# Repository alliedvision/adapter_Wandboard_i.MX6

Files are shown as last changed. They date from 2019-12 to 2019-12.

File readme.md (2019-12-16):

# Allied Vision Adapter Board CSI-2 for Wandboard i.MX6

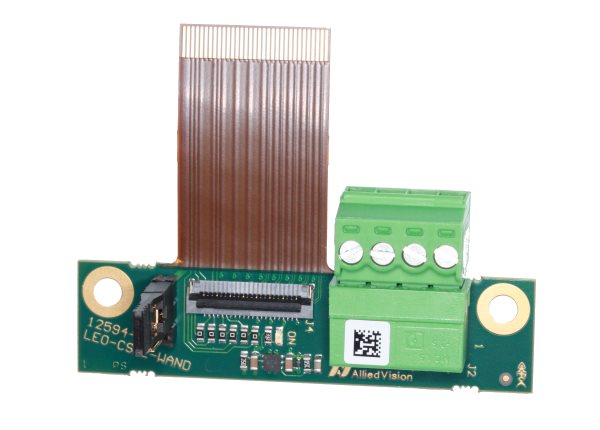
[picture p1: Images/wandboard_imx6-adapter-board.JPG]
wandboard_imx6-adapter-board


This repository contains open hardware design files for an adapter board supporting the Allied Vision Alvium CSI-2 camera pinout to Wandboards i.MX6 based devices, created by Allied Vision.
The board allows the user to interface with one Alvium MIPI CSI-2 compatible camera over a Flexible Flat Cable (FFC) connector.

This adapter can also be ordered at [Allied Vision](https://www.alliedvision.com/en/meta-header/contact-us/contact-sales.html) or a [qualified Allied Vision distributor](https://www.alliedvision.com/en/about-us/where-we-are.html) under order code **12362** - Adapter Board CSI-2 Wandboard.

## Getting Started

These instructions will get you a copy of the design files to make your own adapter boards for development and testing purposes. 
The board can be produced and assembled using the provided design files. Please take a look at the mechanical layers for more information regarding the PCB stackup recommended for fabrication. 

See our [website](https://www.alliedvision.com/en/support/technical-documentation/alvium-csi-2-documentation.html) for further documentation and installation guides of the finished boards.

### Prerequisites

* A running installation of Altium.
* A PCB producer & PCBA manufacturer or some soldering skills.
* One supported embedded board Wandboard i.MX6 series, revision D:
	* Wandboard Solo (i.MX6) WB-IMX6S-BW
	* Wandboard Dual (i.MX6) WB-IMX6U-BW
	* Wandboard Quad (i.MX6) WB-IMX6Q-BW
	* Wandboard QuadPlus (i.MX6) WB-IMX6QP-BW
* One supported MIPI CSI-2 FPC cable
	* Allied Vision part numbers #12316, 12317, 12318
* [One Allied Vision Alvium CSI-2 camera](https://www.alliedvision.com/en/products/embedded-vision-cameras.html)

### Installing

Open the *CSI2-WAND_Rev01.PrjPcb* project file in your Altium environment.

## Built With

* [Altium Designer 19](https://www.altium.com/altium-designer/de)
 
## License

This project is licensed under the MIT License - see the [LICENSE](LICENSE) file for details

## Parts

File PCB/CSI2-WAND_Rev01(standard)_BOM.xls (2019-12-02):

 | Bill of Materials | CSI2-WAND_Rev01
 | Project : | CSI2-WAND
 | PCBA : |  | Revision : | 01
 | PCB : |  | Revision : | 01
 | Variant : | standard
 | Schematic : | CSI2-WAND_Rev01 | Schematic.pdf
 | Placement : | CSI2-WAND_Rev01 | Overlay.pdf
 | Report Date : | 28.11.2019 | 09:44
 | Alternative Parts :
Quantity | Designator | Comment | Footprint | Description | Manufacturer | Manufacturer Part Number | KHK Part Number
1 | C1 | 100n | C-0603_1.0 | Capacitor Ceramic SMD/0603/50V/X7R/10% | several | several | K8340023
2 | C2, C3 | 10u | C-0603_1.0 | Capacitor Ceramic SMD/0603/10V/X7T/20%/125°C | several | several | 10509
1 | D1 | GREEN | D-0603-LED | Chip LED green 430mcd | Würth | 150060GS75000 | 8172
1 | D2 | ESD9B5.0ST5G | D-SOD923 | DIODE TVS; 400W; 5.8-7.8V; BIDIRECT | ON Semiconductor | ESD9B5.0ST5G | 7250
1 | J2 | MC 1,5/4-G-3,5 | CON_MiniCon 4pol 3mm5 | Phoenix MC 1,5/4-G-3,5 MiniCon 4polig 3,5mm | Phoenix | MC 1,5/4-G-3,5 | 12637
1 | J3 | CON1x3 | CON 1x3 RM2.54 | Stiftleiste; 1x3; 2.54mm; gerade | fischer elektronik | SL 11 124 3 G | K7600610
1 | J4 | CON FFC22_Inverted | J-FH55-22S-0.5SH - Inverted Pins | FFC Connector 0.5mm shielded | Hirose | FH55-22S-0.5SH | 10357
1 | J10 | MC 1,5/4-ST-3,5 |  | Phoenix MC 1,5/4-ST-3,5 MiniCon 4polig 3,5mm | Phoenix | MC 1,5/4-ST-3,5 | 12635
1 | J30 | Jumper | J-JUMPER-2.54 | CON/JUMPER/STC02SYAN; 2-pin; 2.54mm; 3A; FEMALE; VERTICAL; BLACK | several | several | 13444
1 | LA1 | LABEL 7x7mm | PCB LABEL 7x7 | LABEL 7x7mm | several | several
4 | MRK1, MRK2, MRK3, MRK4 | Marker Single Layer | PCB_Marker_Pad_top | Position Marker for PCBs
1 | PCB1 | 12594-02 |  | PCB ML04 | several | 12594-02 | 12594-02
1 | R1 | NL | R-0603_0.6 | Standard Resistor SMD/0603/1%/100mW/TK100
1 | R2 | 3k3 | R-0603_0.6 | Standard Resistor SMD/0603/1%/100mW/TK100 | several | several | K8250070
6 | R3, R4, R5, R6, R7, R8 | 0R0 | R-0603_0.6 | Standard Resistor SMD/0603/1%/100mW/TK100 | several | several | K8250041
2 | R9, R10 | 11k | R-0603_0.6 | Standard Resistor SMD/0603/1%/100mW/TK100 | several | several | K8250147
1 | U1 | NCP380HMUAJAATBG | IC-DFN06_2.0x2.0x0.8 | IC/PWR/LOADSW;1V2-5V5;3A;0R03/WLCSP6/1x1.5x0.63mm | onsemi | NCP380HMUAJAATBG | 13676

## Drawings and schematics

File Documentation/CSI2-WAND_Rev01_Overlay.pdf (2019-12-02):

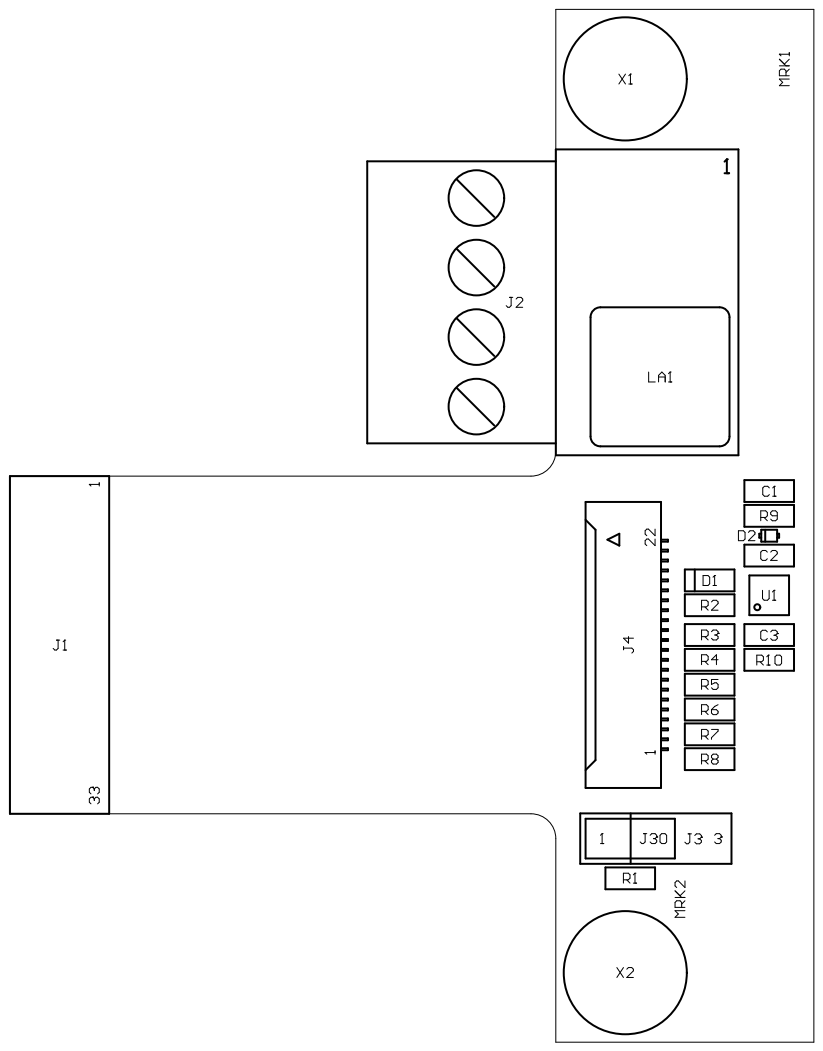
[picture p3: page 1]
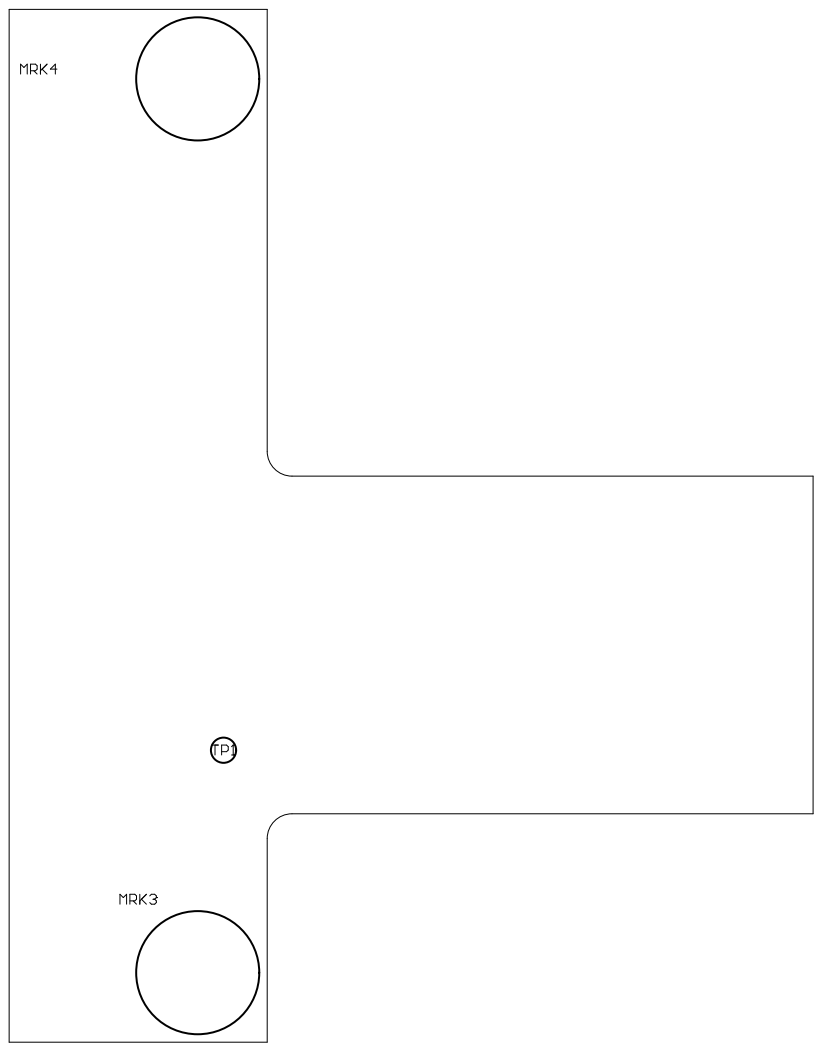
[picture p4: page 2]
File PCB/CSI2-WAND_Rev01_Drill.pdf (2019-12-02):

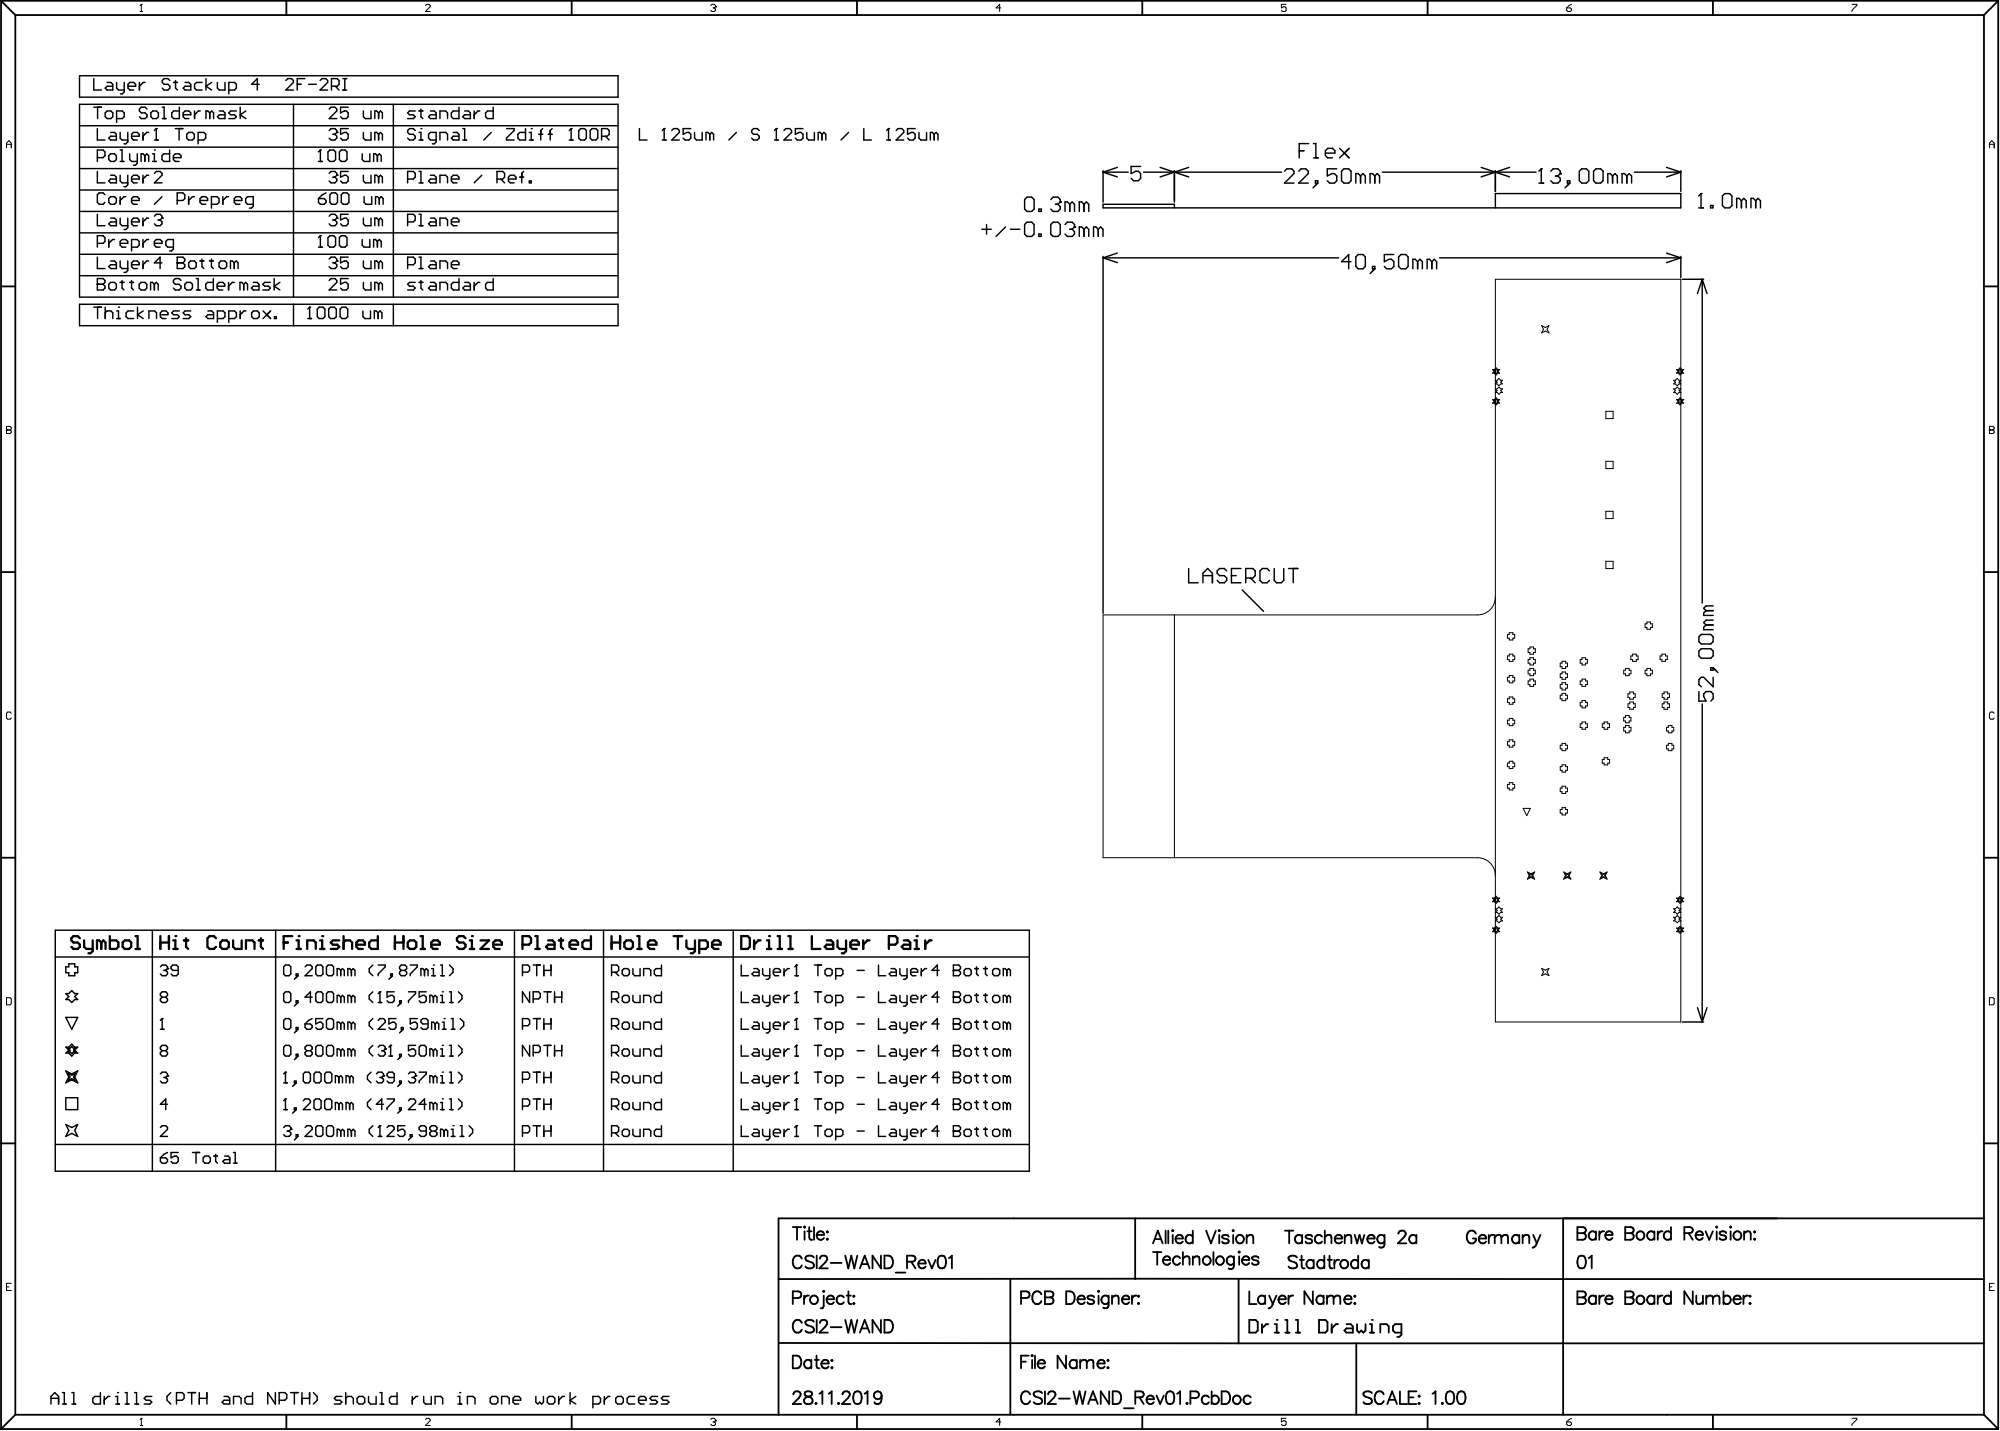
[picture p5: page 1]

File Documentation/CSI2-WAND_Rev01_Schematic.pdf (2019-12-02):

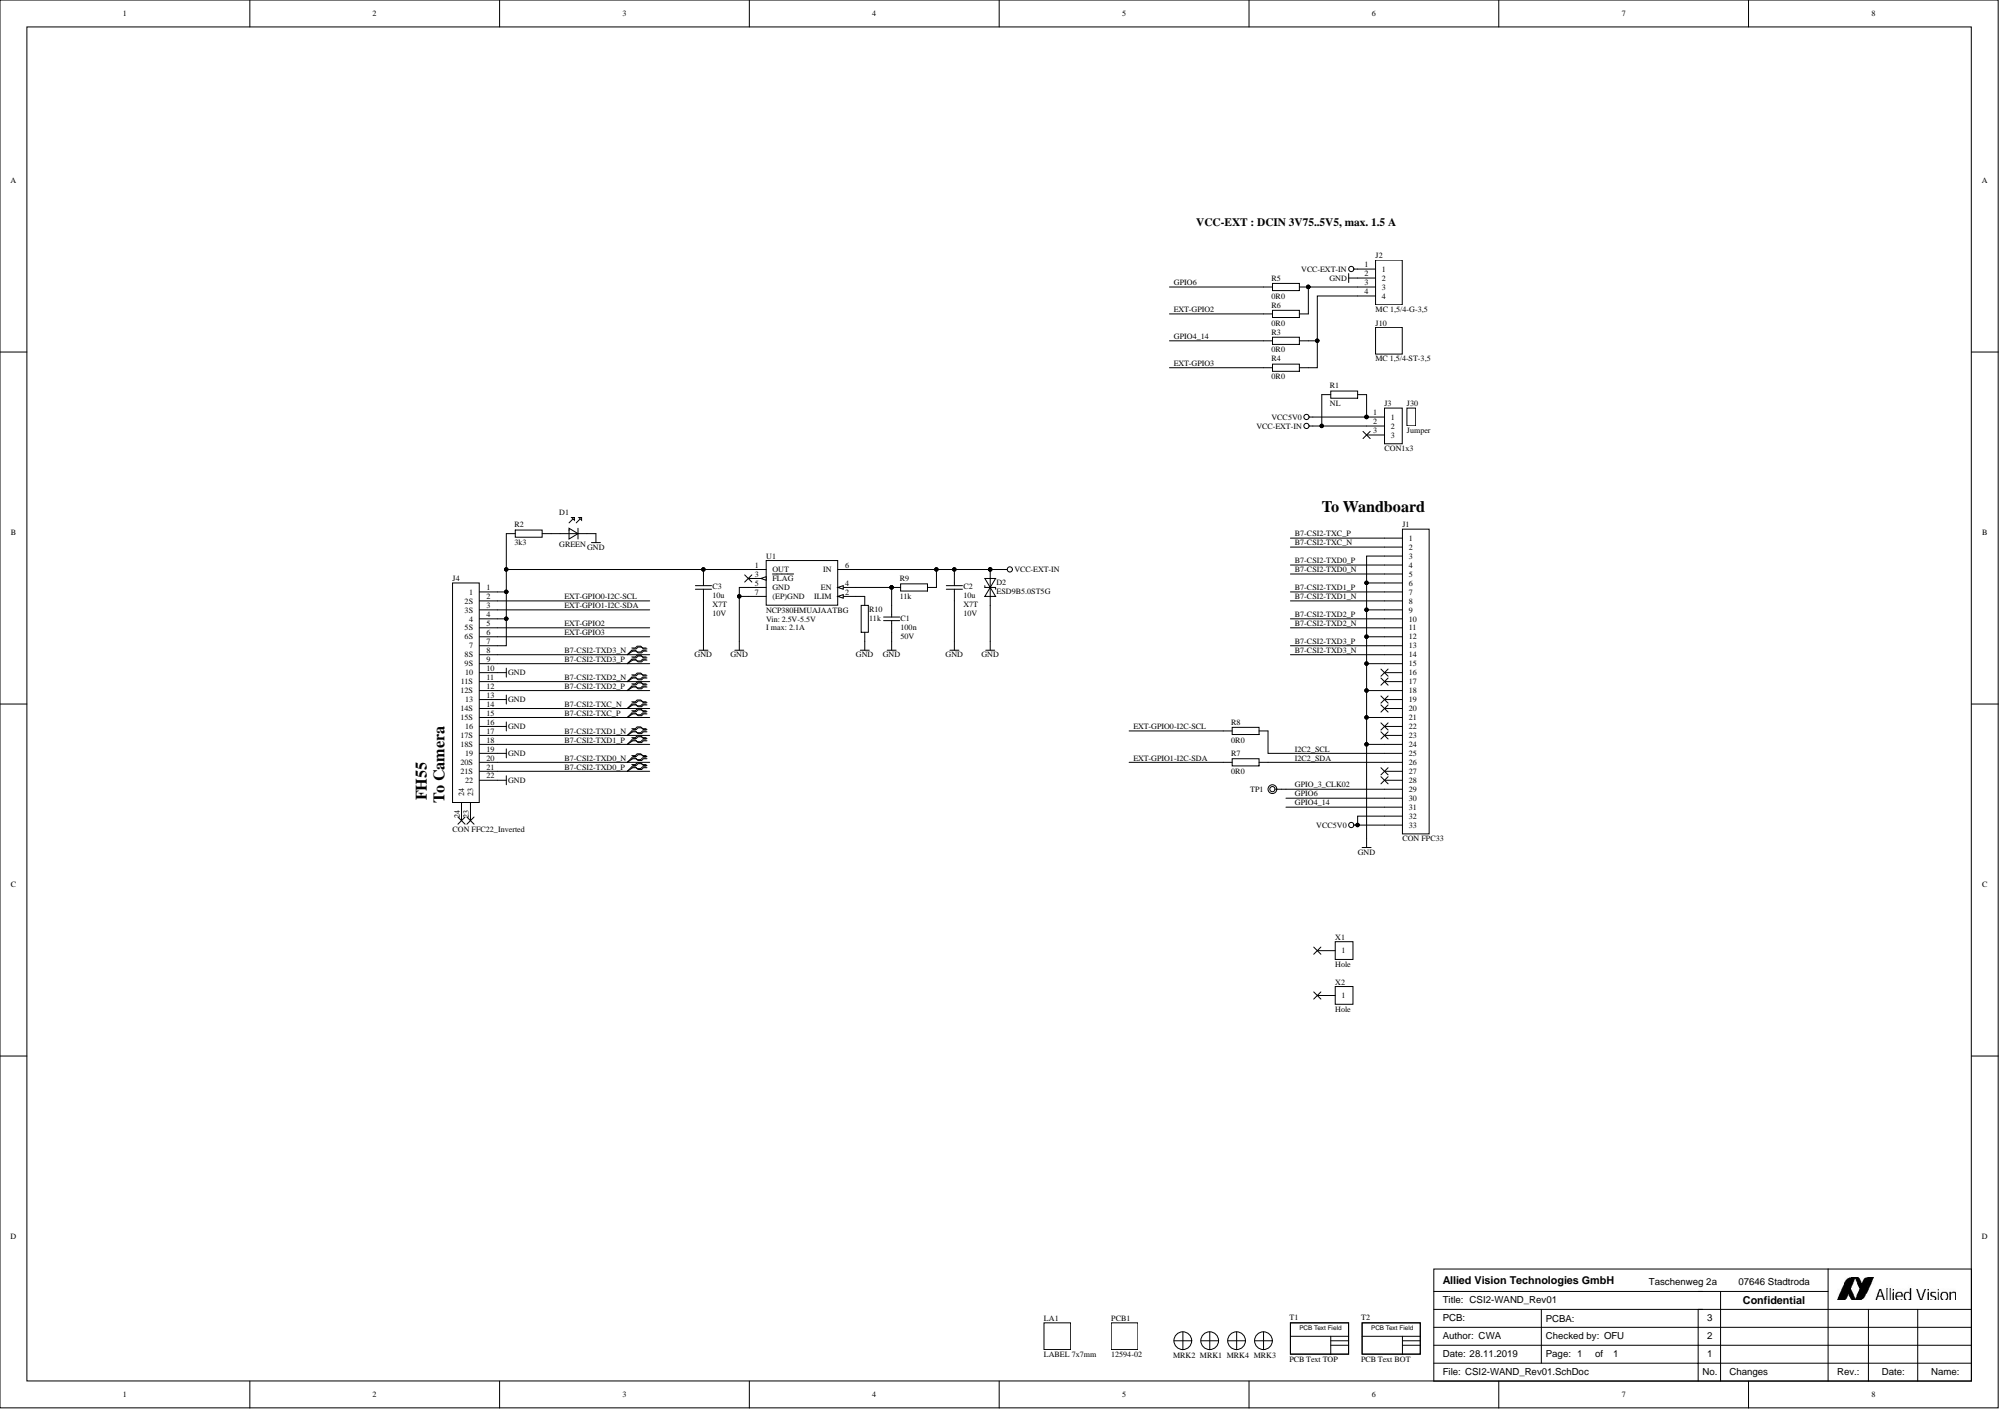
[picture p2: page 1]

VCC-EXT : DCIN 3V75..5V5, max. 1.5 A

Allied Vision Technologies GmbH Taschenweg 2a 07646 Stadtroda

Title: CSI2-WAND_Rev01 | Confidential

Author: CWA | Checked by: OFU | 2

Date: 28.11.2019 | | 1

File: CSI2-WAND_Rev01.SchDoc | | No. | Changes | Rev.: | Date: | Name:
